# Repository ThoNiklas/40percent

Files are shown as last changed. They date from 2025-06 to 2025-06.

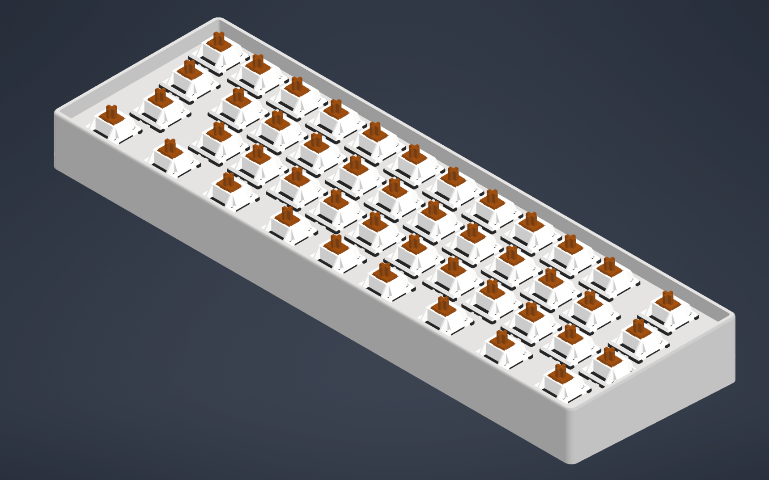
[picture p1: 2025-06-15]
pictures/3Drendering.png

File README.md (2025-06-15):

# 40 percent
Complete design of a 40 % keyboard with 45 keys.

3Drendering
PCBrendering

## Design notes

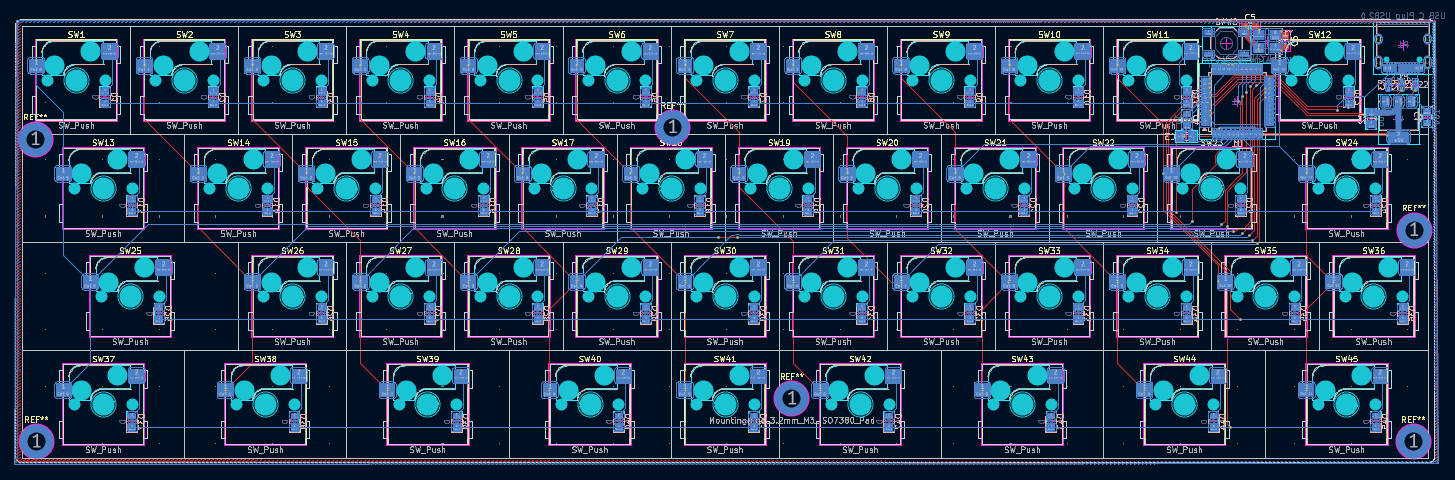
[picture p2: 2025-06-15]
pictures/PCBrendering.png

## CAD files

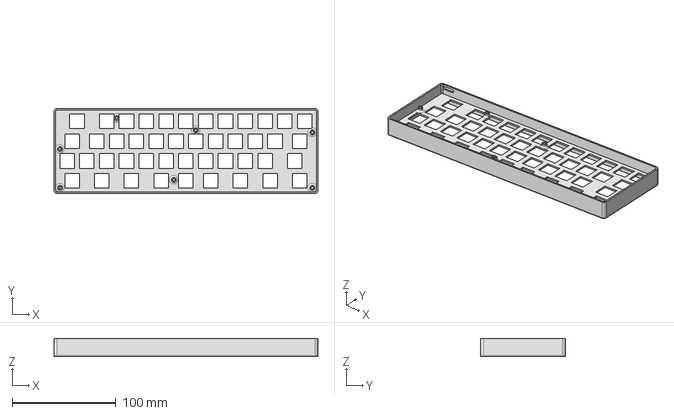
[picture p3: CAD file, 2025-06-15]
case/Top.stp
254.0 x 82.0 x 17.8 mm

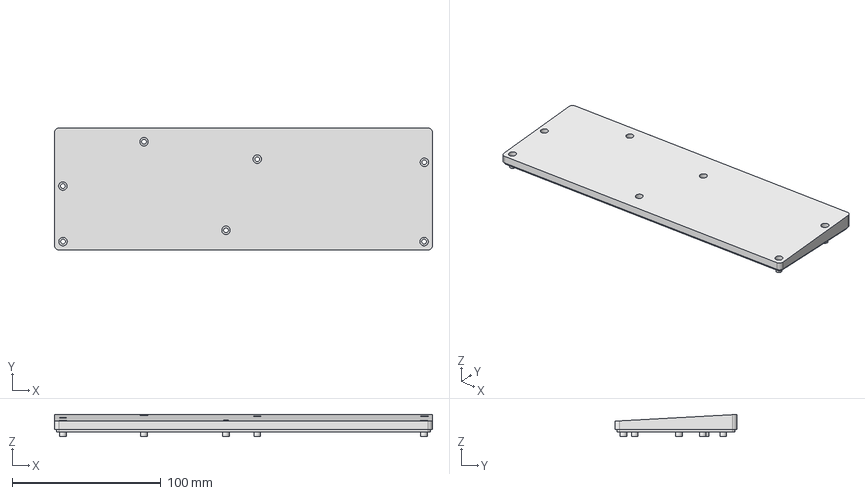
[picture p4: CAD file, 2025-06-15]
case/Bottom.stp
254.0 x 82.0 x 14.9 mm

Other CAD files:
40percent/40percent/40percent/40percent.iam
40percent/40percent/40percent/OldVersions/40percent.0001.iam
case/Bottom.ipt
case/Top.ipt
case/case.iam

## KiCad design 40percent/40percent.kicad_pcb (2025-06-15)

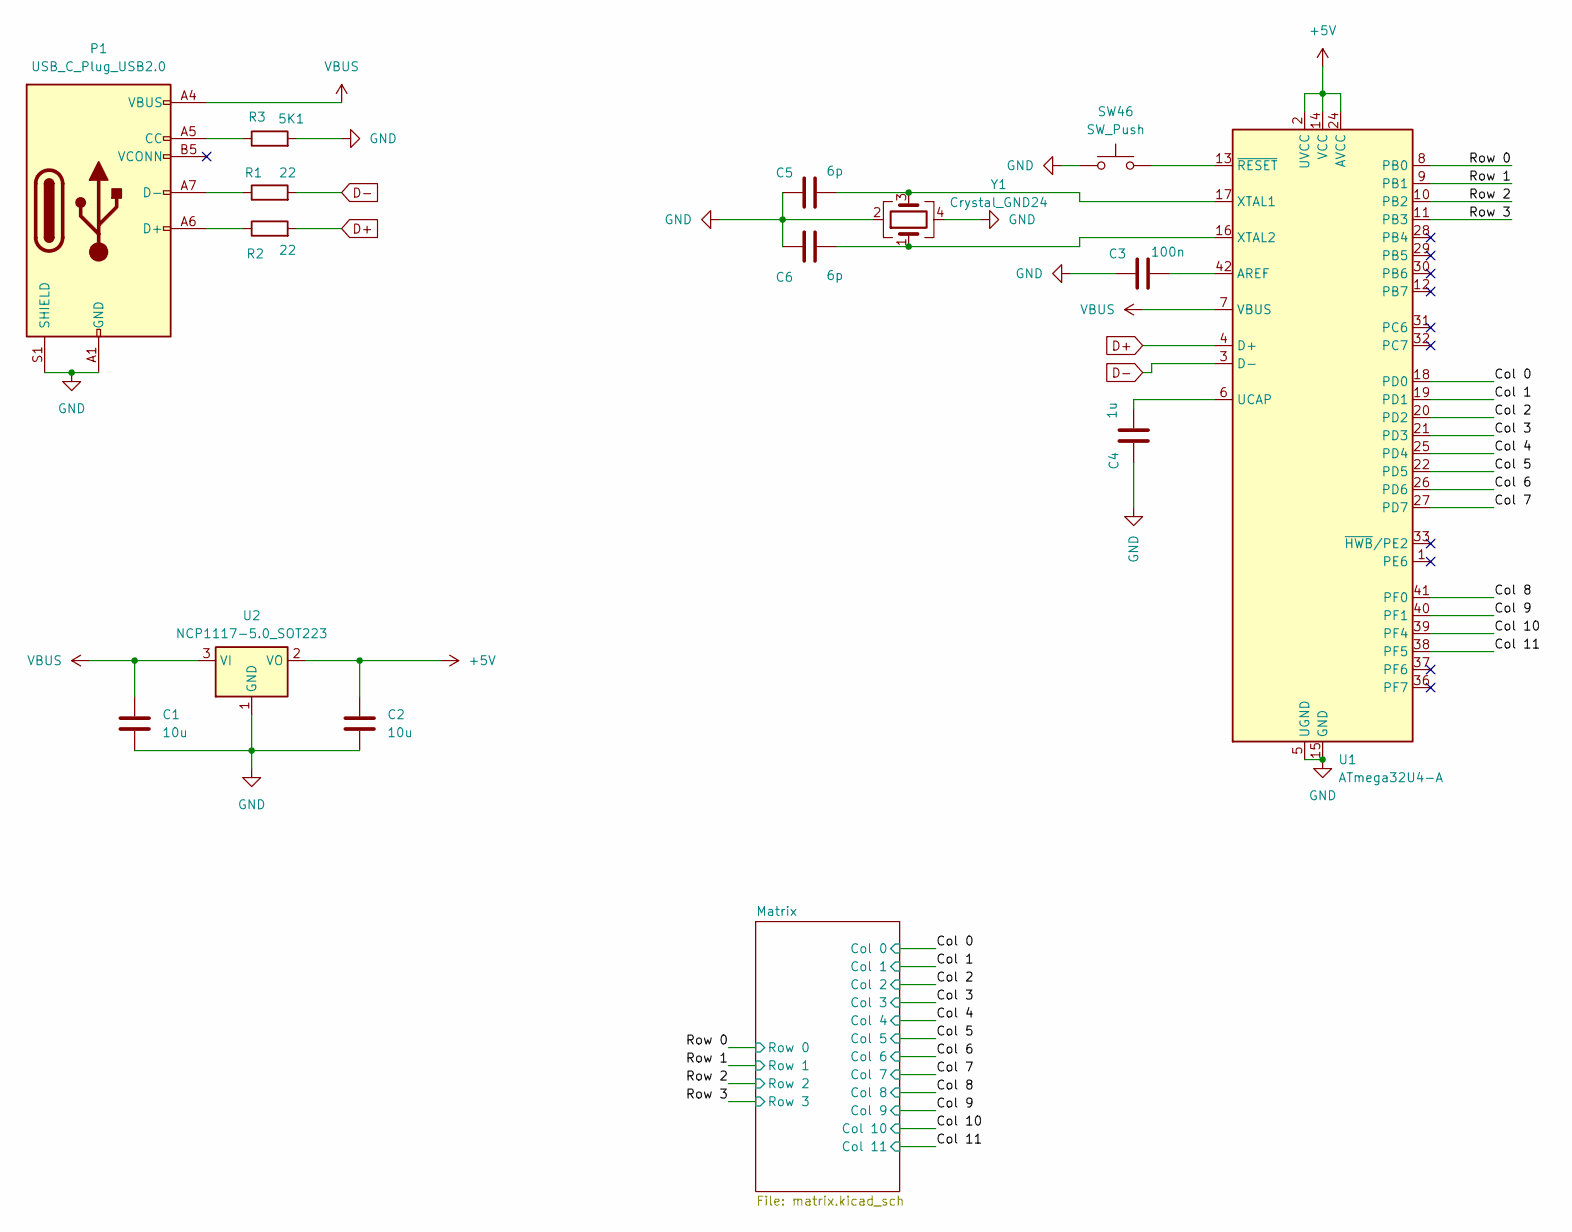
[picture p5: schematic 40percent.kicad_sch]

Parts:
C1, C2: 10u; C_0805_2012Metric_Pad1.18x1.45mm_HandSolder
C3: 100n; C_0805_2012Metric_Pad1.18x1.45mm_HandSolder
C4: 1u; C_0805_2012Metric_Pad1.18x1.45mm_HandSolder
C5, C6: 6p; C_0805_2012Metric_Pad1.18x1.45mm_HandSolder
P1: USB_C_Plug_USB2.0; USB_C_Receptacle_HRO_TYPE-C-31-M-12
R1, R2: 22; R_0402_1005Metric_Pad0.72x0.64mm_HandSolder
R3: 5K1; R_0402_1005Metric_Pad0.72x0.64mm_HandSolder
SW46: SW_Push; SW_SPST_TL3342
U1: ATmega32U4-A; TQFP-44_10x10mm_P0.8mm
U2: NCP1117-5.0_SOT223; SOT-223-3_TabPin2
Y1: Crystal_GND24; Crystal_SMD_3225-4Pin_3.2x2.5mm_HandSoldering

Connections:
+5V: C2.1, U1.2 (UVCC), U1.14 (VCC), U1.24 (AVCC), U1.34 (VCC), U1.44 (AVCC), U2.2 (VO)
/Col 0: U1.18 (PD0); also elsewhere on the board
/Col 1: U1.19 (PD1); also elsewhere on the board
/Col 2: U1.20 (PD2); also elsewhere on the board
/Col 3: U1.21 (PD3); also elsewhere on the board
/Col 4: U1.25 (PD4); also elsewhere on the board
/Col 5: U1.22 (PD5); also elsewhere on the board
/Col 6: U1.26 (PD6); also elsewhere on the board
/Col 7: U1.27 (PD7); also elsewhere on the board
/Col 8: U1.41 (PF0); also elsewhere on the board
/Col 9: U1.40 (PF1); also elsewhere on the board
/Col 10: U1.39 (PF4); also elsewhere on the board
/Col 11: U1.38 (PF5); also elsewhere on the board
/Row 0: U1.8 (PB0); also elsewhere on the board
/Row 1: U1.9 (PB1); also elsewhere on the board
/Row 2: U1.10 (PB2); also elsewhere on the board
/Row 3: U1.11 (PB3); also elsewhere on the board
D+: R2.2, U1.4 (D+)
D-: R1.2, U1.3 (D-)
GND: C1.2, C2.2, C3.1, C4.1, C5.1, C6.1, P1.A1 (GND), P1.A12 (GND), P1.B1 (GND), P1.B12 (GND), P1.S1 (SHIELD), R3.2, SW46.1, U1.5 (UGND), U1.15 (GND), U1.23 (GND), U1.35 (GND), U1.43 (GND), U2.1 (GND), Y1.2, Y1.4
unnamed: P1.A5 (CC), R3.1
unnamed: P1.A6 (D+), R2.1
unnamed: P1.A7 (D-), R1.1
unnamed: C3.2, U1.42 (AREF)
unnamed: C4.2, U1.6 (UCAP)
unnamed: C5.2, U1.17 (XTAL1), Y1.3
unnamed: C6.2, U1.16 (XTAL2), Y1.1
unnamed: SW46.2, U1.13 (~RESET)
VBUS: C1.1, P1.A4 (VBUS), P1.A9 (VBUS), P1.B4 (VBUS), P1.B9 (VBUS), U1.7 (VBUS), U2.3 (VI)

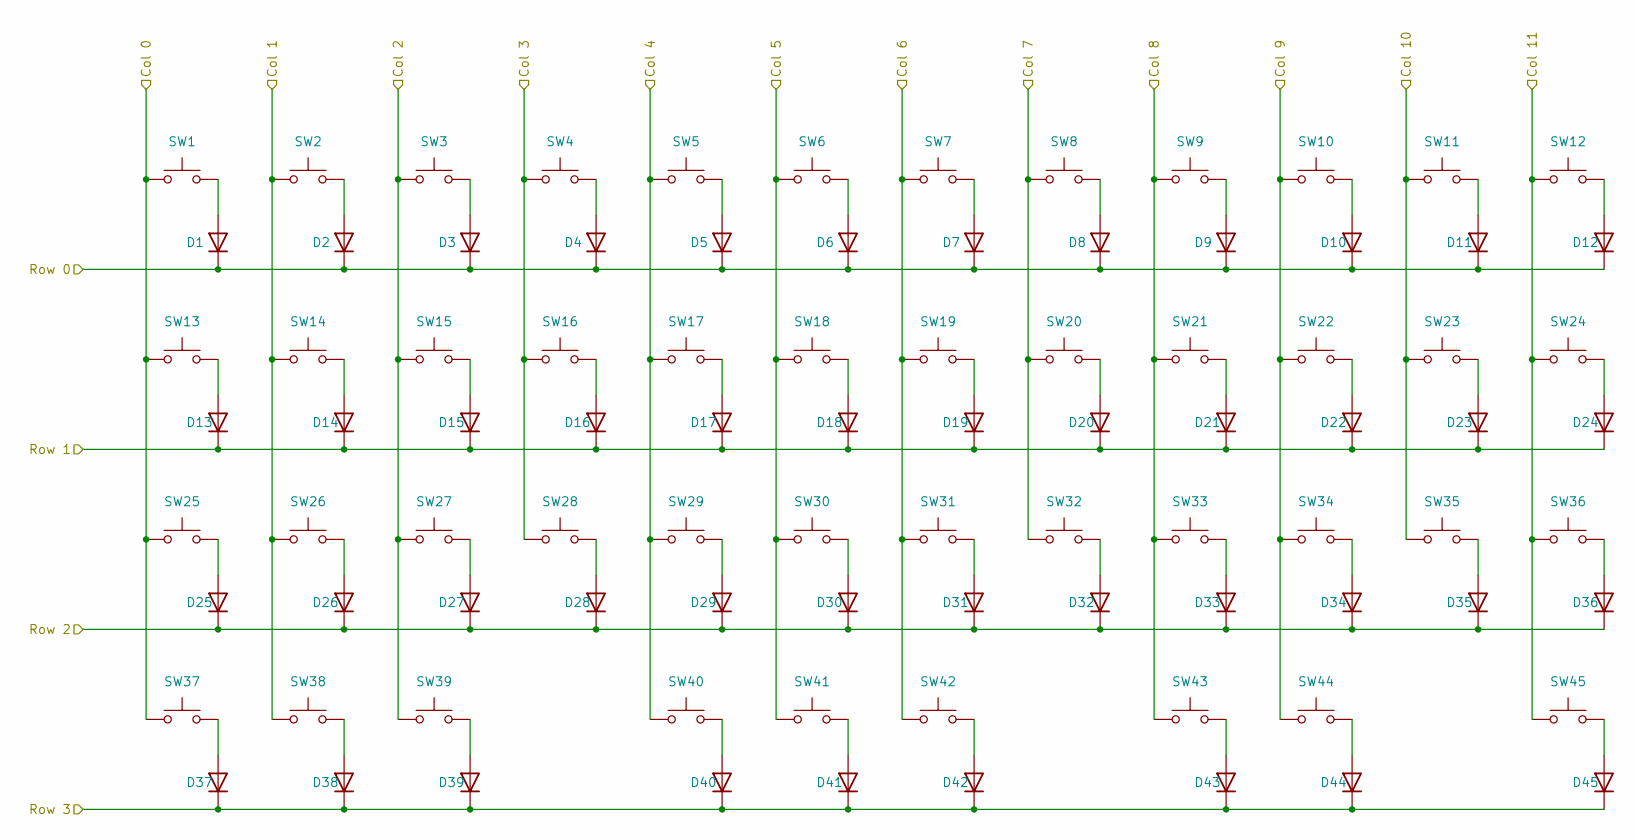
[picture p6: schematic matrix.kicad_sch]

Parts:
D1, D2, D3, D4, D5, D6, D7, D8, D9, D10, D11, D12, D13, D14, D15, D16, D17, D18, D19, D20, D21, D22, D23, D24, D25, D26, D27, D28, D29, D30, D31, D32, D33, D34, D35, D36, D37, D38, D39, D40, D41, D42, D43, D44, D45: D; D_0805_2012Metric_Pad1.15x1.40mm_HandSolder
SW1, SW2, SW3, SW4, SW5, SW6, SW7, SW8, SW9, SW10, SW11, SW14, SW15, SW16, SW17, SW18, SW19, SW20, SW21, SW22, SW23, SW26, SW27, SW28, SW29, SW30, SW31, SW32, SW33, SW34, SW35, SW36, SW41: SW_Push; SW_Hotswap_Kailh_MX_1.00u
SW12, SW25: SW_Push; SW_Hotswap_Kailh_MX_2.00u
SW13, SW24, SW37, SW38, SW39, SW40, SW42, SW43, SW44, SW45: SW_Push; SW_Hotswap_Kailh_MX_1.50u

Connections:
/Col 0: SW1.1, SW13.1, SW25.1, SW37.1; also elsewhere on the board
/Col 1: SW2.1, SW14.1, SW26.1, SW38.1; also elsewhere on the board
/Col 2: SW3.1, SW15.1, SW27.1, SW39.1; also elsewhere on the board
/Col 3: SW4.1, SW16.1, SW28.1; also elsewhere on the board
/Col 4: SW5.1, SW17.1, SW29.1, SW40.1; also elsewhere on the board
/Col 5: SW6.1, SW18.1, SW30.1, SW41.1; also elsewhere on the board
/Col 6: SW7.1, SW19.1, SW31.1, SW42.1; also elsewhere on the board
/Col 7: SW8.1, SW20.1, SW32.1; also elsewhere on the board
/Col 8: SW9.1, SW21.1, SW33.1, SW43.1; also elsewhere on the board
/Col 9: SW10.1, SW22.1, SW34.1, SW44.1; also elsewhere on the board
/Col 10: SW11.1, SW23.1, SW35.1; also elsewhere on the board
/Col 11: SW12.1, SW24.1, SW36.1, SW45.1; also elsewhere on the board
/Row 0: D1.1 (K), D2.1 (K), D3.1 (K), D4.1 (K), D5.1 (K), D6.1 (K), D7.1 (K), D8.1 (K), D9.1 (K), D10.1 (K), D11.1 (K), D12.1 (K); also elsewhere on the board
/Row 1: D13.1 (K), D14.1 (K), D15.1 (K), D16.1 (K), D17.1 (K), D18.1 (K), D19.1 (K), D20.1 (K), D21.1 (K), D22.1 (K), D23.1 (K), D24.1 (K); also elsewhere on the board
/Row 2: D25.1 (K), D26.1 (K), D27.1 (K), D28.1 (K), D29.1 (K), D30.1 (K), D31.1 (K), D32.1 (K), D33.1 (K), D34.1 (K), D35.1 (K), D36.1 (K); also elsewhere on the board
/Row 3: D37.1 (K), D38.1 (K), D39.1 (K), D40.1 (K), D41.1 (K), D42.1 (K), D43.1 (K), D44.1 (K), D45.1 (K); also elsewhere on the board
unnamed: D1.2 (A), SW1.2
unnamed: D2.2 (A), SW2.2
unnamed: D3.2 (A), SW3.2
unnamed: D4.2 (A), SW4.2
unnamed: D5.2 (A), SW5.2
unnamed: D6.2 (A), SW6.2
unnamed: D7.2 (A), SW7.2
unnamed: D8.2 (A), SW8.2
unnamed: D9.2 (A), SW9.2
unnamed: D10.2 (A), SW10.2
unnamed: D11.2 (A), SW11.2
unnamed: D12.2 (A), SW12.2
unnamed: D13.2 (A), SW13.2
unnamed: D14.2 (A), SW14.2
unnamed: D15.2 (A), SW15.2
unnamed: D16.2 (A), SW16.2
unnamed: D17.2 (A), SW17.2
unnamed: D18.2 (A), SW18.2
unnamed: D19.2 (A), SW19.2
unnamed: D20.2 (A), SW20.2
unnamed: D21.2 (A), SW21.2
unnamed: D22.2 (A), SW22.2
unnamed: D23.2 (A), SW23.2
unnamed: D24.2 (A), SW24.2
unnamed: D25.2 (A), SW25.2
unnamed: D26.2 (A), SW26.2
unnamed: D27.2 (A), SW27.2
unnamed: D28.2 (A), SW28.2
unnamed: D29.2 (A), SW29.2
unnamed: D30.2 (A), SW30.2
unnamed: D31.2 (A), SW31.2
unnamed: D32.2 (A), SW32.2
unnamed: D33.2 (A), SW33.2
unnamed: D34.2 (A), SW34.2
unnamed: D35.2 (A), SW35.2
unnamed: D36.2 (A), SW36.2
unnamed: D37.2 (A), SW37.2
unnamed: D38.2 (A), SW38.2
unnamed: D39.2 (A), SW39.2
unnamed: D40.2 (A), SW40.2
unnamed: D41.2 (A), SW41.2
unnamed: D42.2 (A), SW42.2
unnamed: D43.2 (A), SW43.2
unnamed: D44.2 (A), SW44.2
unnamed: D45.2 (A), SW45.2

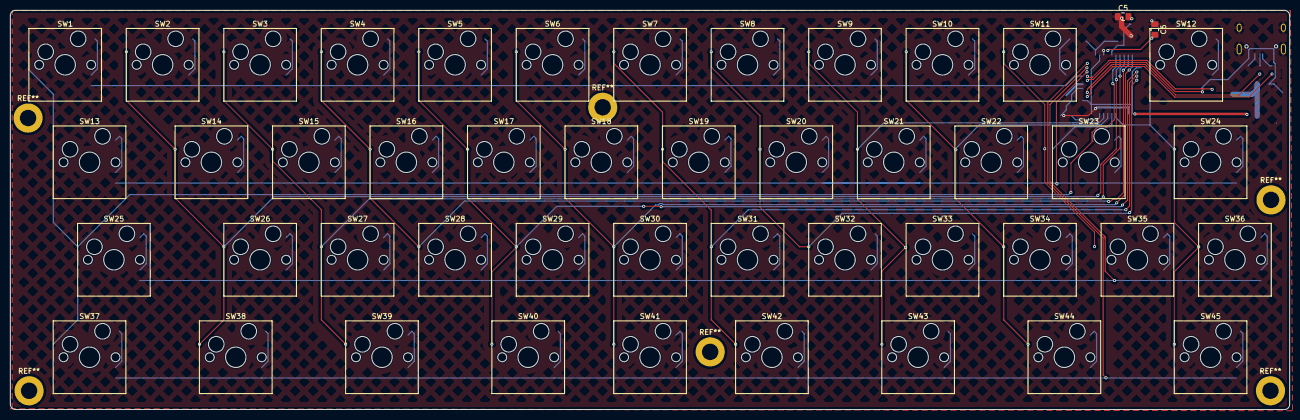
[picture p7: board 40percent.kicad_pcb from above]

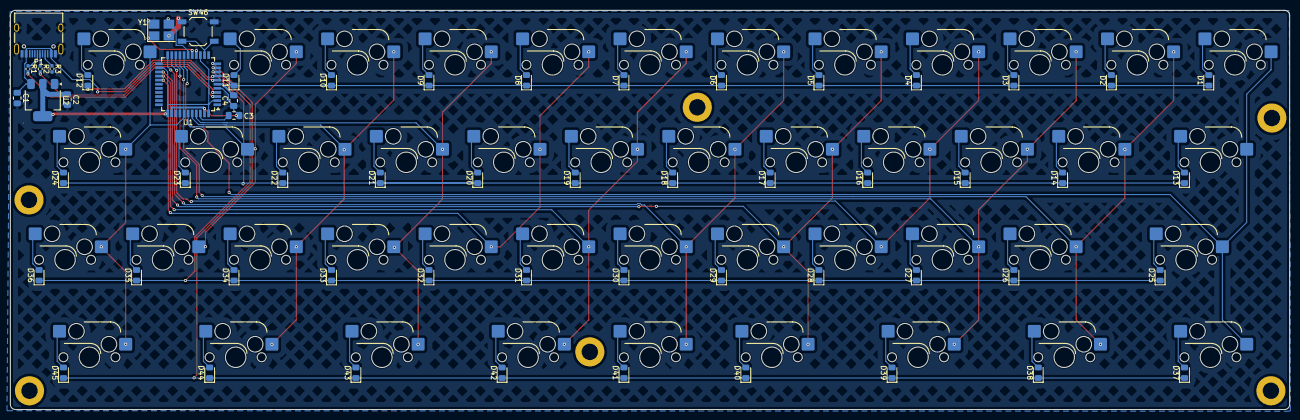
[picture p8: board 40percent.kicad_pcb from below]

Board: 2 copper layers, 250.0 x 78.0 mm, 104 parts (57 on the bottom side), 74 nets.
